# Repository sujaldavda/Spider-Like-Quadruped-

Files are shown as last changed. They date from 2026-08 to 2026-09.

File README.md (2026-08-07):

Quadruped Robot

A 4-legged, 12-DOF quadruped robot designed and developed
to explore mechanical design, electronics integration,
robot kinematics and coordinated multi-servo control.

Demo Video:
https://drive.google.com/file/d/1aahqjPfIVHdNBdxC4B8d9cbAuSaYIsEc/view

Hardware:
- ESP8266
- 12x SG90 Servo Motors
- PCA9685 Servo Driver
- XL4015 Buck Converter
- 2S 18650 Battery Pack

Mechanical Design:
- 3 DOF per leg
- 12 DOF total
- 3D printed structure
- CAD designed in SolidWorks

Control:
- Forward Kinematics
- Inverse Kinematics
- Coordinated gait control

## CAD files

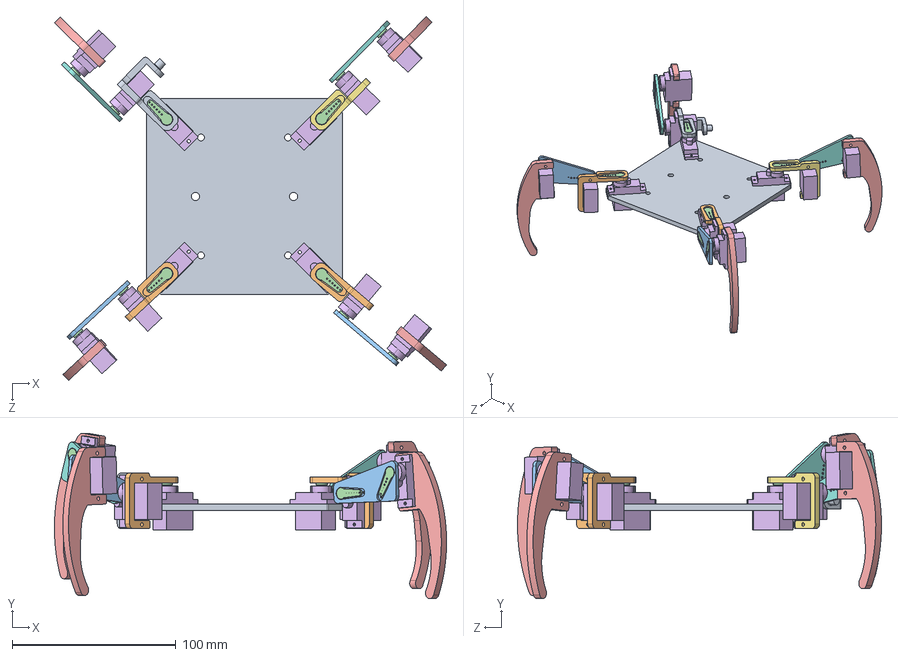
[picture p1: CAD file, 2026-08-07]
robot_description/CAD files/assembly.SLDASM
239.6 x 101.0 x 222.4 mm
base 5.0
clamp 1 redesigned x 2
mid clamp redesign x 2
servo horn x 12
tibia RD x 4
Servo_motor.step x 12
Mirrorclamp 1 redesigned
Mirrormid clamp redesign-------------------- x 2
clamp 1 remake

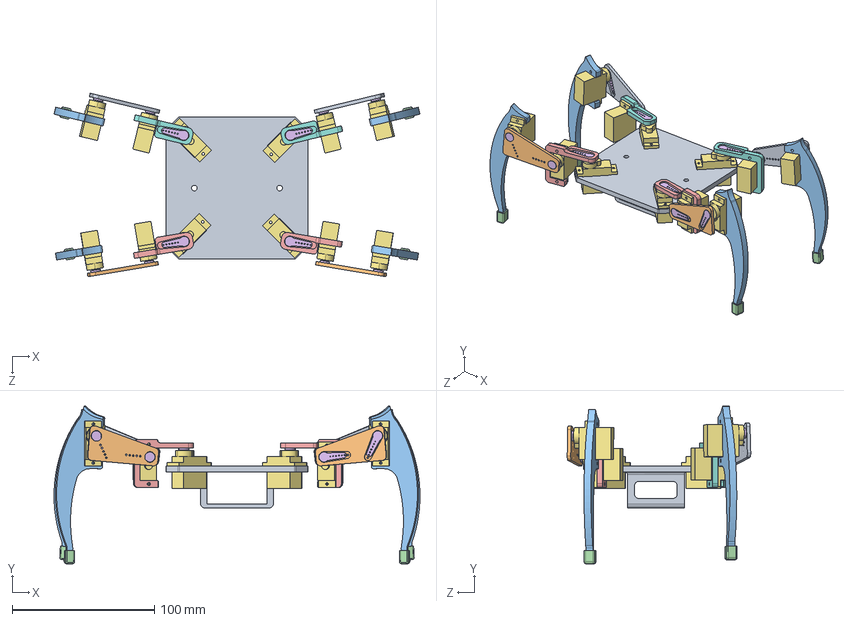
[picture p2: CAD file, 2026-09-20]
robot_description/meshes/Assem IK.SLDASM
257.5 x 110.9 x 129.2 mm
base 5.0 remake
mid clamp redesign x 2
tibia RD x 4
tibia tip x 4
clamp 1 redesigned x 2
servo horn x 12
Servo_motor.step x 12
Mirrorclamp 1 redesigned x 2
Mirrormid clamp redesign-------------------- x 2

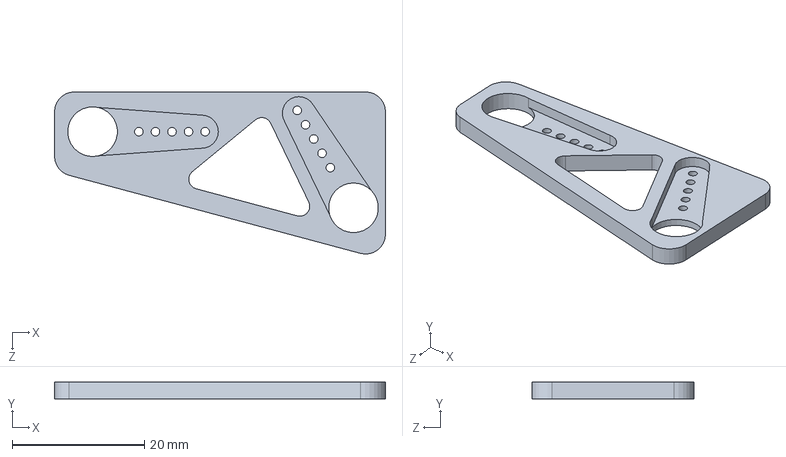
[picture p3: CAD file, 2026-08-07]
robot_description/CAD files/Mirrormid clamp redesign--------------------.SLDPRT
50.0 x 2.50 x 24.5 mm

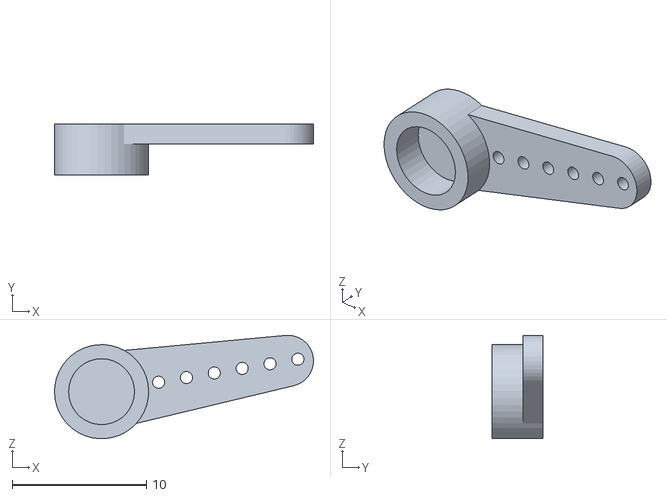
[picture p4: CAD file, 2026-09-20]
robot_description/meshes/quadrapod reddit - servo horn-1.STL
19.3 x 3.80 x 7.68

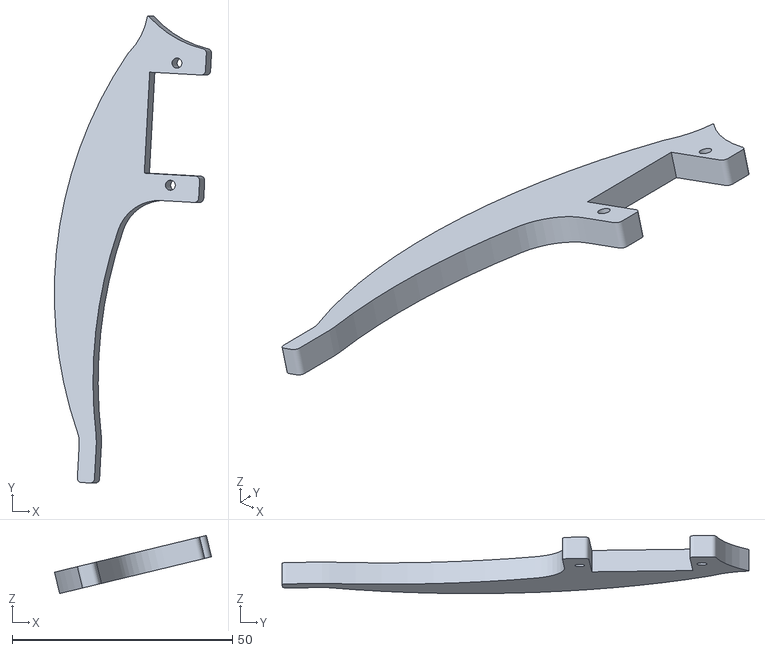
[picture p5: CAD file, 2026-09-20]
robot_description/meshes/quadrapod reddit - tibia RD-3.STL
35.7 x 106.1 x 13.2

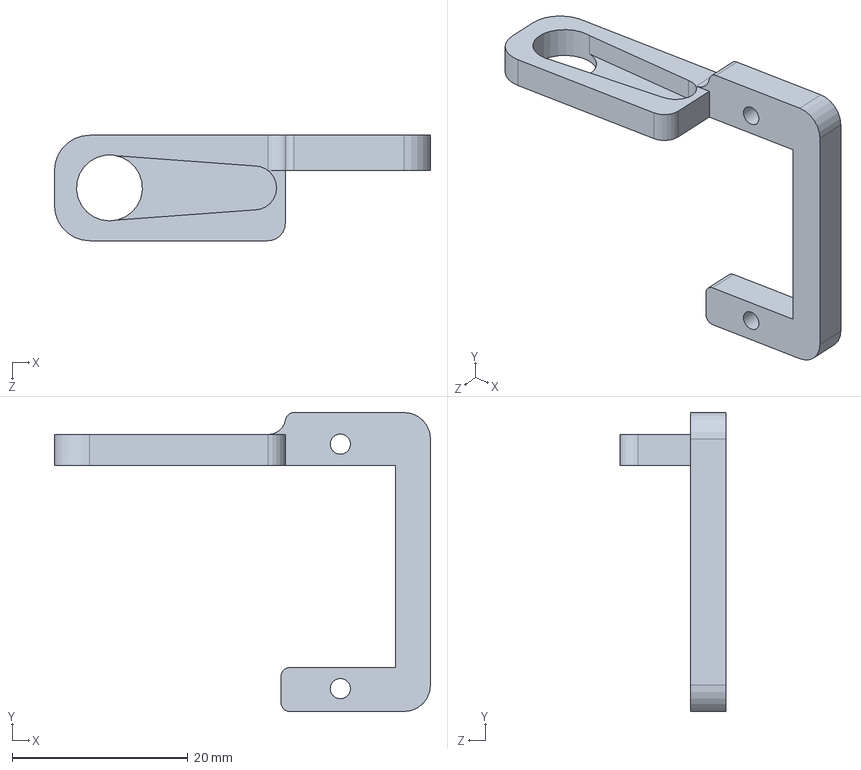
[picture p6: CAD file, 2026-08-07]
robot_description/CAD files/clamp 1 redesigned.SLDPRT
42.8 x 34.0 x 12.0 mm

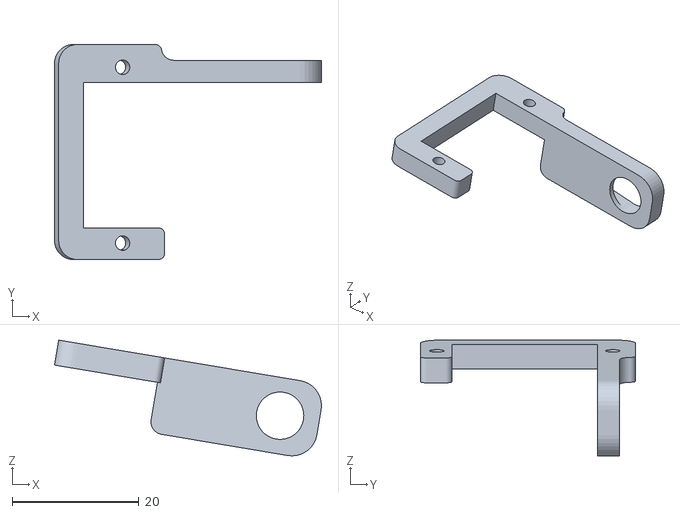
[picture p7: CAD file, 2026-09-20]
robot_description/meshes/quadrapod reddit - clamp 1 redesigned-2.STL
42.2 x 34.0 x 18.3

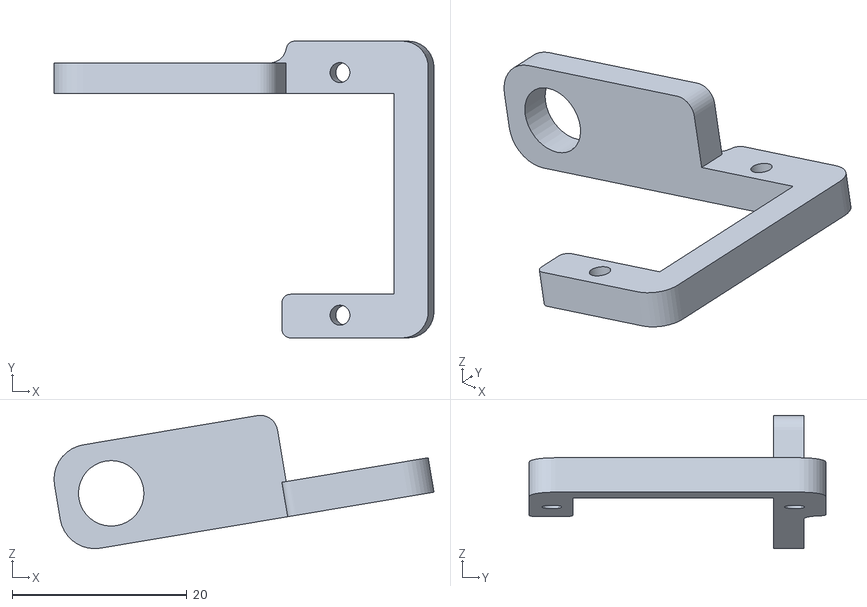
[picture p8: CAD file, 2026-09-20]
robot_description/meshes/quadrapod reddit - clamp 1 redesigned-1.STL
43.5 x 34.0 x 15.3

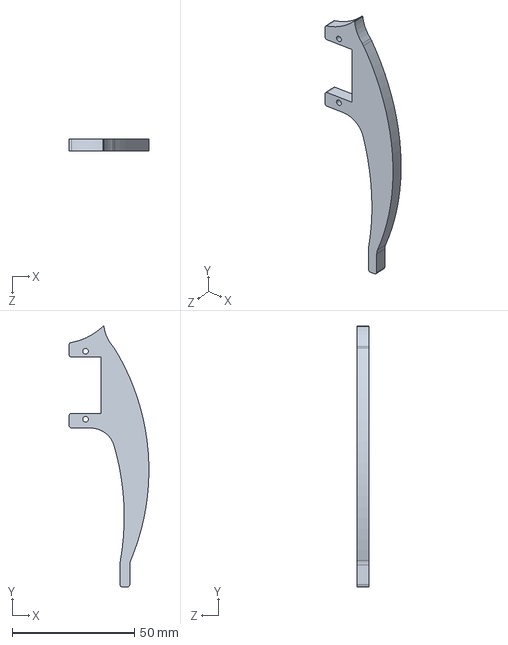
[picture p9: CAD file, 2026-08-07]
robot_description/CAD files/tibia RD.SLDPRT
32.6 x 106.7 x 5.00 mm

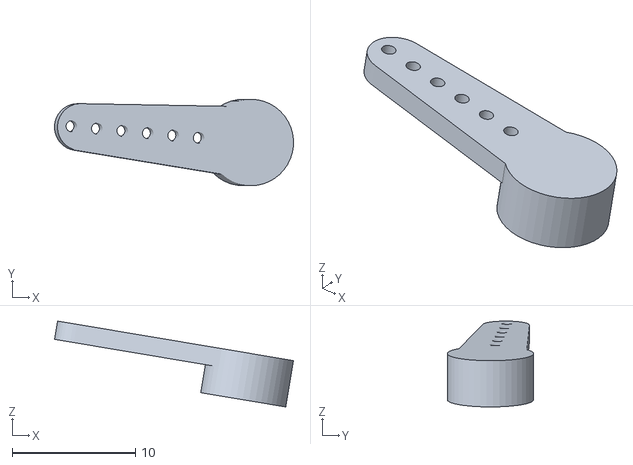
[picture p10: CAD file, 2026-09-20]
robot_description/meshes/quadrapod reddit - servo horn-11.STL
19.4 x 7.00 x 6.96

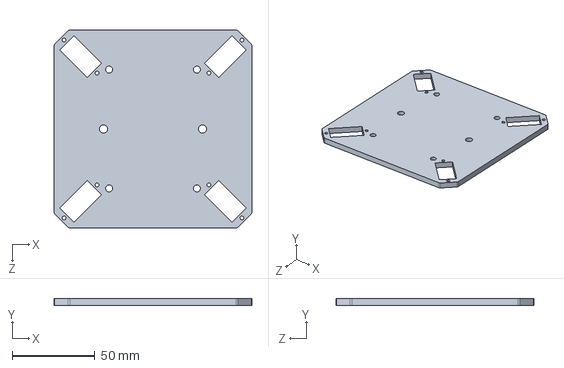
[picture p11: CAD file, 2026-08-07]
robot_description/CAD files/base 5.0.SLDPRT
120.0 x 4.00 x 120.0 mm

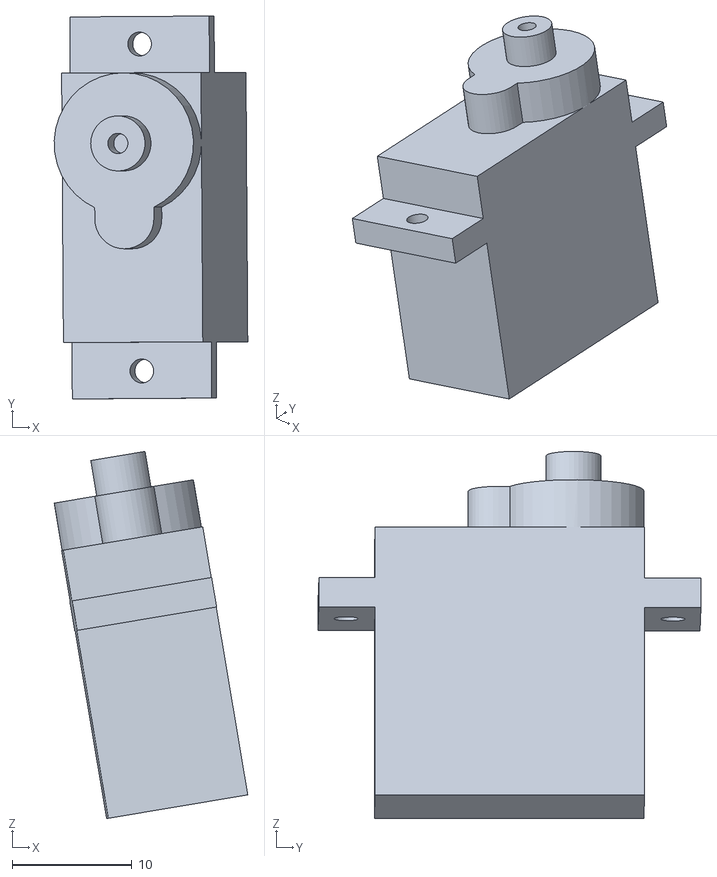
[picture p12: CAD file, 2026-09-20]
robot_description/meshes/quadrapod reddit - Servo_motor.step-3.STL
16.2 x 32.0 x 30.7

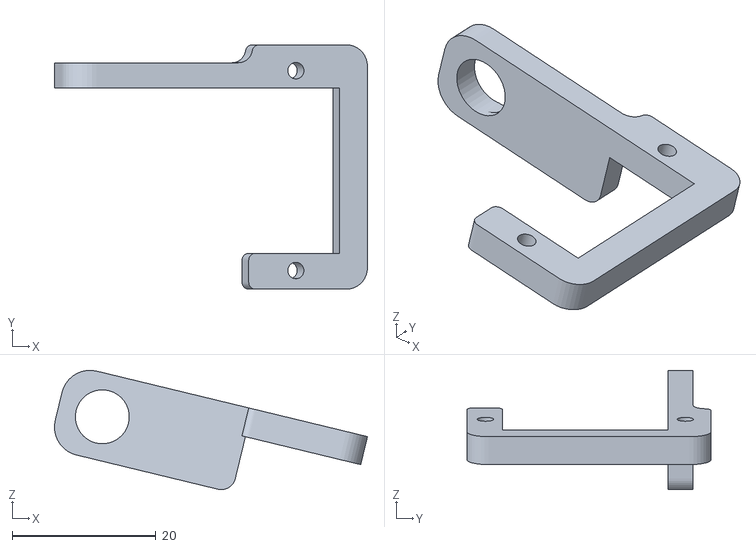
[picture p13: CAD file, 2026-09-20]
robot_description/meshes/quadrapod reddit - Mirrorclamp 1 redesigned-1.STL
43.5 x 34.0 x 16.6

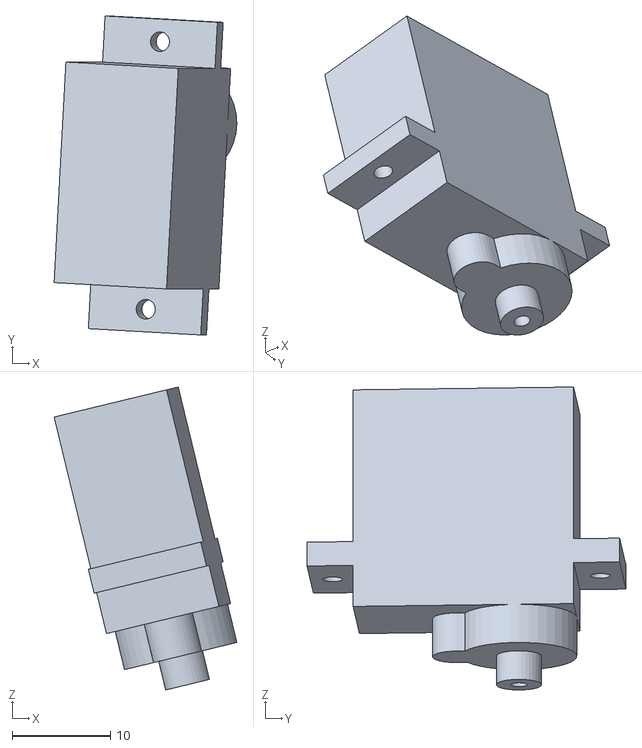
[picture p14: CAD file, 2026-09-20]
robot_description/meshes/quadrapod reddit - Servo_motor.step-10.STL
18.6 x 32.5 x 30.9

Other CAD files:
robot_description/CAD files/mid clamp redesign.SLDPRT
robot_description/CAD files/Mirrorclamp 1 redesigned.SLDPRT
robot_description/meshes/quadrapod reddit - servo horn-12.STL
robot_description/meshes/quadrapod reddit - Servo_motor.step-11.STL
robot_description/meshes/quadrapod reddit - Mirrorclamp 1 redesigned-2.STL
robot_description/meshes/quadrapod reddit - Mirrormid clamp redesign---------------------1.STL
robot_description/meshes/quadrapod reddit - Mirrormid clamp redesign---------------------2.STL
robot_description/meshes/quadrapod reddit - Servo_motor.step-1.STL
robot_description/meshes/quadrapod reddit - Servo_motor.step-12.STL
robot_description/meshes/quadrapod reddit - Servo_motor.step-2.STL
robot_description/meshes/quadrapod reddit - Servo_motor.step-4.STL
robot_description/meshes/quadrapod reddit - Servo_motor.step-5.STL
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

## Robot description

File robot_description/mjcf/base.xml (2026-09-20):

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
<mujoco model="spider_quadruped">
  <compiler angle="radian" meshdir="../meshes/" autolimits="true"/>
  <option timestep="0.001" integrator="implicitfast"/>

  <default>
    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
    <joint damping="0.02" armature="0.0005" frictionloss="0.001" range="-1.5708 1.5708"/>
    <position kp="3" kv="0.03" forcerange="-0.2 0.2" inheritrange="1"/>
    <default class="visual">
      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
      <default class="servo">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</default>
      <default class="horn">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</default>
    </default>
    <default class="collision">
      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
    </default>
  </default>

  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

  <worldbody>
    <body name="base_link" pos="0 0 0.06" childclass="visual">
      <freejoint name="root"/>
      <inertial pos="0 0 0.0086" mass="0.2025" fullinertia="7.194e-05 7.012e-05 1.310e-04 0 0 0"/>
      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
      <body name="FL_coxa" pos="0.03752 0.037166 0.02855">
        <joint name="FL_coxa_joint" axis="0 0 1" range="-1.5708 0.5236"/>
        <inertial pos="-0.00046952 0.025303 -0.011077" mass="0.010901" fullinertia="1.3433e-06 1.1827e-06 1.1172e-06 7.7895e-08 -6.036e-08 2.6762e-07"/>
        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
        <body name="FL_femur" pos="0.016051 0.024277 -0.0074">
          <joint name="FL_femur_joint" axis="0.9862 -0.1656 0"/>
          <inertial pos="0.0037466 0.020988 0.0058263" mass="0.0024496" fullinertia="6.2957e-07 1.2071e-07 5.4206e-07 -8.8356e-08 -2.2326e-08 -1.359e-07"/>
          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
          <body name="FL_tibia" pos="0.0063376 0.037747 0.014863">
            <joint name="FL_tibia_joint" axis="0.9862 -0.1656 0" range="-0.9948 1.5708"/>
            <inertial pos="-0.015733 0.0077231 -0.013664" mass="0.014061" fullinertia="7.1221e-06 6.6603e-06 1.4786e-06 -1.1556e-07 2.9199e-07 1.6351e-06"/>
            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
          </body>
        </body>
      </body>

      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
      <body name="RL_coxa" pos="-0.037166 0.03752 0.02855">
        <joint name="RL_coxa_joint" axis="0 0 1" range="-0.5760 1.5708"/>
        <inertial pos="-0.0013273 0.025273 -0.010665" mass="0.010901" fullinertia="1.3421e-06 1.161e-06 1.1172e-06 -6.574e-08 4.0386e-08 2.6305e-07"/>
        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
        <body name="RL_femur" pos="-0.017733 0.023077 -0.0069">
          <joint name="RL_femur_joint" axis="-0.972 -0.2352 0"/>
          <inertial pos="-0.005173 0.020448 0.0066131" mass="0.0024496" fullinertia="6.1528e-07 1.4603e-07 5.3144e-07 1.2108e-07 3.5638e-08 -1.4931e-07"/>
          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
          <body name="RL_tibia" pos="-0.0088641 0.036639 0.016275">
            <joint name="RL_tibia_joint" axis="-0.972 -0.2352 0" range="-1.5708 0.9948"/>
            <inertial pos="0.014988 0.0094516 -0.013408" mass="0.014061" fullinertia="7.0932e-06 6.518e-06 1.65e-06 1.8779e-07 -4.667e-07 1.8427e-06"/>
            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
          </body>
        </body>
      </body>

      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
      <body name="RR_coxa" pos="-0.03752 -0.037166 0.02855">
        <joint name="RR_coxa_joint" axis="0 0 1" range="-1.5708 0.5760"/>
        <inertial pos="-0.0015781 -0.02548 -0.010665" mass="0.010901" fullinertia="1.3287e-06 1.2335e-06 1.1761e-06 4.6707e-08 3.4993e-08 -2.6174e-07"/>
        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
        <body name="RR_femur" pos="-0.01738 -0.023431 -0.0069">
          <joint name="RR_femur_joint" axis="-0.972 0.2352 0"/>
          <inertial pos="-0.0052527 -0.020428 0.0066131" mass="0.0024496" fullinertia="6.1521e-07 1.461e-07 5.3144e-07 -1.2122e-07 3.5146e-08 1.4943e-07"/>
          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
          <body name="RR_tibia" pos="-0.0088641 -0.036639 0.016275">
            <joint name="RR_tibia_joint" axis="-0.972 0.2352 0" range="-1.0996 1.5708"/>
            <inertial pos="0.014988 -0.0094516 -0.013408" mass="0.014061" fullinertia="7.0932e-06 6.518e-06 1.65e-06 -1.8779e-07 -4.667e-07 -1.8427e-06"/>
            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
          </body>
        </body>
      </body>

      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
      <body name="FR_coxa" pos="0.037166 -0.03752 0.02855">
        <joint name="FR_coxa_joint" axis="0 0 1" range="-0.5236 1.5708"/>
        <inertial pos="0.00049728 -0.024847 -0.011077" mass="0.010901" fullinertia="1.333e-06 1.252e-06 1.1761e-06 -5.2976e-08 -5.7648e-08 -2.6716e-07"/>
        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
        <body name="FR_femur" pos="0.016404 -0.023924 -0.0074">
          <joint name="FR_femur_joint" axis="0.9862 0.1656 0"/>
          <inertial pos="0.0038275 -0.020974 0.0058263" mass="0.0024496" fullinertia="6.2952e-07 1.2075e-07 5.4205e-07 8.8493e-08 -2.1821e-08 1.3599e-07"/>
          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
          <body name="FR_tibia" pos="0.0063376 -0.037747 0.014863">
            <joint name="FR_tibia_joint" axis="0.9862 0.1656 0" range="-1.5708 0.9948"/>
            <inertial pos="-0.015733 -0.0077231 -0.013664" mass="0.014061" fullinertia="7.1221e-06 6.6603e-06 1.4786e-06 1.1556e-07 2.9199e-07 -1.6351e-06"/>
            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
          </body>
        </body>
      </body>
    </body>
  </worldbody>

  <actuator>
    <position name="FL_coxa" joint="FL_coxa_joint"/>
    <position name="FL_femur" joint="FL_femur_joint"/>
    <position name="FL_tibia" joint="FL_tibia_joint"/>
    <position name="RL_coxa" joint="RL_coxa_joint"/>
    <position name="RL_femur" joint="RL_femur_joint"/>
    <position name="RL_tibia" joint="RL_tibia_joint"/>
    <position name="RR_coxa" joint="RR_coxa_joint"/>
    <position name="RR_femur" joint="RR_femur_joint"/>
    <position name="RR_tibia" joint="RR_tibia_joint"/>
    <position name="FR_coxa" joint="FR_coxa_joint"/>
    <position name="FR_femur" joint="FR_femur_joint"/>
    <position name="FR_tibia" joint="FR_tibia_joint"/>
  </actuator>

  <sensor>
    <framequat name="imu_quat" objtype="site" objname="imu"/>
    <gyro name="imu_gyro" site="imu"/>
    <accelerometer name="imu_acc" site="imu"/>
  </sensor>

  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
</mujoco>

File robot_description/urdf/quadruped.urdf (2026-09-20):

<?xml version="1.0"?>
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
<robot name="spider_quadruped">

  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
  <link name="base_link">
    <inertial>
      <origin xyz="0 0 0.0086" rpy="0 0 0"/>
      <mass value="0.2025"/>
      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
    </inertial>
    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
  </link>

  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
  <joint name="FL_coxa_joint" type="revolute">
    <parent link="base_link"/><child link="FL_coxa"/>
    <origin xyz="0.03752 0.037166 0.02855" rpy="0 0 0"/>
    <axis xyz="0 0 1"/>
    <limit lower="-1.5708" upper="0.5236" effort="0.2" velocity="10.5"/>
    <dynamics damping="0.02" friction="0.0"/>
  </joint>
  <link name="FL_coxa">
    <inertial>
      <origin xyz="-0.00046952 0.025303 -0.011077" rpy="0 0 0"/>
      <mass value="0.010901"/>
      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
    </inertial>
    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
  </link>

  <joint name="FL_femur_joint" type="revolute">
    <parent link="FL_coxa"/><child link="FL_femur"/>
    <origin xyz="0.016051 0.024277 -0.0074" rpy="0 0 0"/>
    <axis xyz="0.9862 -0.1656 0"/>
    <limit lower="-1.5708" upper="1.5708" effort="0.2" velocity="10.5"/>
    <dynamics damping="0.02" friction="0.0"/>
  </joint>
  <link name="FL_femur">
    <inertial>
      <origin xyz="0.0037466 0.020988 0.0058263" rpy="0 0 0"/>
      <mass value="0.0024496"/>
      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
    </inertial>
    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
  </link>

  <joint name="FL_tibia_joint" type="revolute">
    <parent link="FL_femur"/><child link="FL_tibia"/>
    <origin xyz="0.0063376 0.037747 0.014863" rpy="0 0 0"/>
    <axis xyz="0.9862 -0.1656 0"/>
    <limit lower="-0.9948" upper="1.5708" effort="0.2" velocity="10.5"/>
    <dynamics damping="0.02" friction="0.0"/>
  </joint>
  <link name="FL_tibia">
    <inertial>
      <origin xyz="-0.015733 0.0077231 -0.013664" rpy="0 0 0"/>
      <mass value="0.014061"/>
      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
    </inertial>
    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
  </link>

  <joint name="FL_foot_joint" type="fixed">
    <parent link="FL_tibia"/><child link="FL_foot"/>
    <origin xyz="-0.01356 0.018587 -0.089869" rpy="0 0 0"/>
  </joint>
  <link name="FL_foot"/>

  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
  <joint name="RL_coxa_joint" type="revolute">
    <parent link="base_link"/><child link="RL_coxa"/>
    <origin xyz="-0.037166 0.03752 0.02855" rpy="0 0 0"/>
    <axis xyz="0 0 1"/>
    <limit lower="-0.5760" upper="1.5708" effort="0.2" velocity="10.5"/>
    <dynamics damping="0.02" friction="0.0"/>
  </joint>
  <link name="RL_coxa">
    <inertial>
      <origin xyz="-0.0013273 0.025273 -0.010665" rpy="0 0 0"/>
      <mass value="0.010901"/>
      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
    </inertial>
    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
  </link>

  <joint name="RL_femur_joint" type="revolute">
    <parent link="RL_coxa"/><child link="RL_femur"/>
    <origin xyz="-0.017733 0.023077 -0.0069" rpy="0 0 0"/>
    <axis xyz="-0.972 -0.2352 0"/>
    <limit lower="-1.5708" upper="1.5708" effort="0.2" velocity="10.5"/>
    <dynamics damping="0.02" friction="0.0"/>
  </joint>
  <link name="RL_femur">
    <inertial>
      <origin xyz="-0.005173 0.020448 0.0066131" rpy="0 0 0"/>
      <mass value="0.0024496"/>
      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
    </inertial>
    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
  </link>

  <joint name="RL_tibia_joint" type="revolute">
    <parent link="RL_femur"/><child link="RL_tibia"/>
    <origin xyz="-0.0088641 0.036639 0.016275" rpy="0 0 0"/>
    <axis xyz="-0.972 -0.2352 0"/>
    <limit lower="-1.5708" upper="0.9948" effort="0.2" velocity="10.5"/>
    <dynamics damping="0.02" friction="0.0"/>
  </joint>
  <link name="RL_tibia">
    <inertial>
      <origin xyz="0.014988 0.0094516 -0.013408" rpy="0 0 0"/>
      <mass value="0.014061"/>
      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
    </inertial>
    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
  </link>

  <joint name="RL_foot_joint" type="fixed">
    <parent link="RL_tibia"/><child link="RL_foot"/>
    <origin xyz="0.011155 0.022571 -0.089045" rpy="0 0 0"/>
  </joint>
  <link name="RL_foot"/>

  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
  <joint name="RR_coxa_joint" type="revolute">
    <parent link="base_link"/><child link="RR_coxa"/>
    <origin xyz="-0.03752 -0.037166 0.02855" rpy="0 0 0"/>
    <axis xyz="0 0 1"/>
    <limit lower="-1.5708" upper="0.5760" effort="0.2" velocity="10.5"/>
    <dynamics damping="0.02" friction="0.0"/>
  </joint>
  <link name="RR_coxa">
    <inertial>
      <origin xyz="-0.0015781 -0.02548 -0.010665" rpy="0 0 0"/>
      <mass value="0.010901"/>
      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
    </inertial>
    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
  </link>

  <joint name="RR_femur_joint" type="revolute">
    <parent link="RR_coxa"/><child link="RR_femur"/>
    <origin xyz="-0.01738 -0.023431 -0.0069" rpy="0 0 0"/>
    <axis xyz="-0.972 0.2352 0"/>
    <limit lower="-1.5708" upper="1.5708" effort="0.2" velocity="10.5"/>
    <dynamics damping="0.02" friction="0.0"/>
  </joint>
  <link name="RR_femur">
    <inertial>
      <origin xyz="-0.0052527 -0.020428 0.0066131" rpy="0 0 0"/>
      <mass value="0.0024496"/>
      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
    </inertial>
    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
  </link>

  <joint name="RR_tibia_joint" type="revolute">
    <parent link="RR_femur"/><child link="RR_tibia"/>
    <origin xyz="-0.0088641 -0.036639 0.016275" rpy="0 0 0"/>
    <axis xyz="-0.972 0.2352 0"/>
    <limit lower="-1.0996" upper="1.5708" effort="0.2" velocity="10.5"/>
    <dynamics damping="0.02" friction="0.0"/>
  </joint>
  <link name="RR_tibia">
    <inertial>
      <origin xyz="0.014988 -0.0094516 -0.013408" rpy="0 0 0"/>
      <mass value="0.014061"/>
      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
    </inertial>
    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
  </link>

  <joint name="RR_foot_joint" type="fixed">
    <parent link="RR_tibia"/><child link="RR_foot"/>
    <origin xyz="0.011155 -0.022571 -0.089045" rpy="0 0 0"/>
  </joint>
  <link name="RR_foot"/>

  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
  <joint name="FR_coxa_joint" type="revolute">
    <parent link="base_link"/><child link="FR_coxa"/>
    <origin xyz="0.037166 -0.03752 0.02855" rpy="0 0 0"/>
    <axis xyz="0 0 1"/>
    <limit lower="-0.5236" upper="1.5708" effort="0.2" velocity="10.5"/>
    <dynamics damping="0.02" friction="0.0"/>
  </joint>
  <link name="FR_coxa">
    <inertial>
      <origin xyz="0.00049728 -0.024847 -0.011077" rpy="0 0 0"/>
      <mass value="0.010901"/>
      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
    </inertial>
    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
  </link>

  <joint name="FR_femur_joint" type="revolute">
    <parent link="FR_coxa"/><child link="FR_femur"/>
    <origin xyz="0.016404 -0.023924 -0.0074" rpy="0 0 0"/>
    <axis xyz="0.9862 0.1656 0"/>
    <limit lower="-1.5708" upper="1.5708" effort="0.2" velocity="10.5"/>
    <dynamics damping="0.02" friction="0.0"/>
  </joint>
  <link name="FR_femur">
    <inertial>
      <origin xyz="0.0038275 -0.020974 0.0058263" rpy="0 0 0"/>
      <mass value="0.0024496"/>
      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
    </inertial>
    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
  </link>
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

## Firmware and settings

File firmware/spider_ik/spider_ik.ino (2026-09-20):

// =====================================================
// SPIDER-LIKE QUADRUPED - 3-DOF IK (all 4 legs)
// ESP8266 + PCA9685 + 12x SG90
// =====================================================
// Coordinates: body frame, mm. Origin = centre of base plate,
// x forward, y left, z up. Same frame as model/quadruped.urdf.
// Joint angles: deg, 0 = CAD assembly pose.
//
// Serial 115200, commands (one per line):
//   help
//   home                      all feet to CAD pose
//   foot FL x y z             move foot to body-frame target
//   rel FL dx dy dz           move foot relative to its home position
//   height dz                 all feet shifted dz from home (negative = body up)
//   joint FL coxa femur tibia set joint angles directly
//   raw ch deg                raw servo angle 0-180 (calibration)
//   where                     print feet and joint angles
// Legs: FL RL RR FR
// =====================================================

#include <Wire.h>
#include <Adafruit_PWMServoDriver.h>
#include "leg_ik.h"

using namespace leg_ik;

Adafruit_PWMServoDriver pca = Adafruit_PWMServoDriver(0x40);

// =====================================================
// PCA9685 / SG90
// =====================================================
#define SERVO_FREQ 50
#define SERVO_MIN 102   // pulse ticks at 0 deg   (~0.5 ms)
#define SERVO_MAX 512   // pulse ticks at 180 deg (~2.5 ms)

// =====================================================
// CALIBRATION  <-- EDIT FOR YOUR ROBOT
// =====================================================
// Index = leg*3 + joint, legs FL RL RR FR, joints coxa femur tibia.
//
// SERVO_CHANNEL: PCA9685 output for each joint.
// SERVO_CENTER : raw servo angle (0-180) that puts the joint in the CAD pose.
//                Find it with "raw ch deg" until the leg matches the CAD.
// SERVO_DIR    : +1 or -1, so positive joint angles move the way the model expects:
//                coxa  +  = leg swings counter-clockwise seen from above (all legs)
//                femur +  = foot UP on FL and RR, foot DOWN on RL and FR
//                tibia +  = foot tip swings outward on FL and RR, inward on RL and FR
//                Test with e.g. "joint FL 0 10 0" and flip the sign if it moves the wrong way.
const uint8_t SERVO_CHANNEL[12] = {
  0, 1, 2,     // FL
  3, 4, 5,     // RL
  6, 7, 8,     // RR
  9, 10, 11    // FR
};
float SERVO_CENTER[12] = {
  90, 90, 90,
  90, 90, 90,
  90, 90, 90,
  90, 90, 90
};
int8_t SERVO_DIR[12] = {
  1, 1, 1,
  1, 1, 1,
  1, 1, 1,
  1, 1, 1
};

// =====================================================
// MOTION
// =====================================================
const unsigned long MOVE_MS = 400;   // duration of a foot move
const unsigned long STEP_MS = 20;    // update period (one servo frame)

float homePos[4][3];   // foot positions at CAD pose
float curPos[4][3];    // current commanded foot positions
Joints curJoints[4];

// =====================================================
// SERVO OUTPUT
// =====================================================
void writeServoRaw(uint8_t index, float deg)
{
  deg = constrain(deg, 0.0, 180.0);
  int pulse = SERVO_MIN + (int)(deg / 180.0 * (SERVO_MAX - SERVO_MIN) + 0.5);
  pca.setPWM(SERVO_CHANNEL[index], 0, pulse);
}

bool writeLeg(int leg, const Joints &q)
{
  float qa[3] = {q.coxa, q.femur, q.tibia};
  float raw[3];
  for (int j = 0; j < 3; j++) {
    int i = leg * 3 + j;
    raw[j] = SERVO_CENTER[i] + SERVO_DIR[i] * qa[j];
    if (raw[j] < 0 || raw[j] > 180) {
      Serial.printf("ERROR: %s joint %d needs servo %.1f deg (outside 0-180), check SERVO_CENTER\n",
                    LEGS[leg].name, j, raw[j]);
      return false;
    }
  }
  for (int j = 0; j < 3; j++) writeServoRaw(leg * 3 + j, raw[j]);
  curJoints[leg] = q;
  return true;
}

// =====================================================
// IK WRAPPERS
// =====================================================
const char *resultText(Result r)
{
  switch (r) {
    case TOO_CLOSE:    return "target too close to coxa axis";
    case OUT_OF_REACH: return "target out of reach";
    case JOINT_LIMIT:  return "joint limit";
    default:           return "ok";
  }
}

bool solveLeg(int leg, float x, float y, float z, Joints &q)
{
  Result r = inverse(LEGS[leg], x, y, z, q);
  if (r != OK) {
    Serial.printf("ERROR: %s -> (%.1f, %.1f, %.1f): %s", LEGS[leg].name, x, y, z, resultText(r));
    if (r == JOINT_LIMIT) Serial.printf(" (coxa %.1f femur %.1f tibia %.1f)", q.coxa, q.femur, q.tibia);
    Serial.println();
    return false;
  }
  return true;
}

// Move several feet together along straight lines. Checks the whole path first.
bool moveFeet(float target[4][3], bool active[4])
{
  int steps = max(1UL, MOVE_MS / STEP_MS);
  Joints q[4];

  for (int k = 1; k <= steps; k++) {
    float t = (float)k / steps;
    for (int leg = 0; leg < 4; leg++) {
      if (!active[leg]) continue;
      float p[3];
      for (int a = 0; a < 3; a++) p[a] = curPos[leg][a] + (target[leg][a] - curPos[leg][a]) * t;
      if (!solveLeg(leg, p[0], p[1], p[2], q[leg])) return false;
    }
  }

  unsigned long next = millis();
  for (int k = 1; k <= steps; k++) {
    float t = (float)k / steps;
    for (int leg = 0; leg < 4; leg++) {
      if (!active[leg]) continue;
      float p[3];
      for (int a = 0; a < 3; a++) p[a] = curPos[leg][a] + (target[leg][a] - curPos[leg][a]) * t;
      solveLeg(leg, p[0], p[1], p[2], q[leg]);
      if (!writeLeg(leg, q[leg])) return false;
    }
    next += STEP_MS;
    while (millis() < next) delay(1);
  }
  for (int leg = 0; leg < 4; leg++)
    if (active[leg])
      for (int a = 0; a < 3; a++) curPos[leg][a] = target[leg][a];
  return true;
}

bool moveOneFoot(int leg, float x, float y, float z)
{
  float target[4][3];
  bool active[4] = {false, false, false, false};
  memcpy(target, curPos, sizeof(target));
  target[leg][0] = x; target[leg][1] = y; target[leg][2] = z;
  active[leg] = true;
  return moveFeet(target, active);
}

// =====================================================
// SERIAL COMMANDS
// =====================================================
int legIndex(const char *s)
{
  if (!s) return -1;
  for (int i = 0; i < 4; i++)
    if (toupper(s[0]) == LEGS[i].name[0] && toupper(s[1]) == LEGS[i].name[1] && s[2] == 0) return i;
  return -1;
}

bool readFloats(float *out, int n)
{
  for (int i = 0; i < n; i++) {
    char *tok = strtok(NULL, " ,\t");
    if (!tok) return false;
    out[i] = atof(tok);
  }
  return true;
}

void printWhere()
{
  for (int leg = 0; leg < 4; leg++)
    Serial.printf("%s foot (%.1f, %.1f, %.1f) mm  joints coxa %.1f femur %.1f tibia %.1f deg\n",
                  LEGS[leg].name, curPos[leg][0], curPos[leg][1], curPos[leg][2],
                  curJoints[leg].coxa, curJoints[leg].femur, curJoints[leg].tibia);
}

void printHelp()
{
  Serial.println("home | foot FL x y z | rel FL dx dy dz | height dz | joint FL c f t | raw ch deg | where");
  Serial.println("legs: FL RL RR FR   units: mm, deg   frame: x forward, y left, z up");
}

void handleCommand(char *line)
{
  char *cmd = strtok(line, " ,\t");
  if (!cmd) return;
  float v[4];

  if (!strcmp(cmd, "help")) {
    printHelp();
  }
  else if (!strcmp(cmd, "home")) {
    bool all[4] = {true, true, true, true};
    moveFeet(homePos, all);
  }
  else if (!strcmp(cmd, "foot") || !strcmp(cmd, "rel")) {
    int leg = legIndex(strtok(NULL, " ,\t"));
    if (leg < 0 || !readFloats(v, 3)) { Serial.println("usage: foot FL x y z | rel FL dx dy dz"); return; }
    if (!strcmp(cmd, "rel")) for (int a = 0; a < 3; a++) v[a] += homePos[leg][a];
    moveOneFoot(leg, v[0], v[1], v[2]);
  }
  else if (!strcmp(cmd, "height")) {
    if (!readFloats(v, 1)) { Serial.println("usage: height dz"); return; }
    float target[4][3];
    bool all[4] = {true, true, true, true};
    for (int leg = 0; leg < 4; leg++) {
      target[leg][0] = homePos[leg][0];
      target[leg][1] = homePos[leg][1];
      target[leg][2] = homePos[leg][2] + v[0];
    }
    moveFeet(target, all);
  }
  else if (!strcmp(cmd, "joint")) {
    int leg = legIndex(strtok(NULL, " ,\t"));
    if (leg < 0 || !readFloats(v, 3)) { Serial.println("usage: joint FL coxa femur tibia"); return; }
    Joints q = {v[0], v[1], v[2]};
    const LegGeom &g = LEGS[leg];
    for (int j = 0; j < 3; j++)
      if (v[j] < g.minDeg[j] || v[j] > g.maxDeg[j]) { Serial.printf("ERROR: joint %d outside %.0f..%.0f\n", j, g.minDeg[j], g.maxDeg[j]); return; }
    if (writeLeg(leg, q)) forward(g, q, curPos[leg][0], curPos[leg][1], curPos[leg][2]);
  }
  else if (!strcmp(cmd, "raw")) {
    if (!readFloats(v, 2) || v[0] < 0 || v[0] > 15) { Serial.println("usage: raw ch deg"); return; }
    int ch = (int)v[0];
    float deg = constrain(v[1], 0.0, 180.0);
    pca.setPWM(ch, 0, SERVO_MIN + (int)(deg / 180.0 * (SERVO_MAX - SERVO_MIN) + 0.5));
    Serial.printf("channel %d -> %.1f deg\n", ch, deg);
    return;
  }
  else if (!strcmp(cmd, "where")) {
    printWhere();
    return;
  }
  else {
    Serial.println("unknown command, type help");
    return;
  }
  printWhere();
}

// =====================================================
// SETUP / LOOP
// =====================================================
void setup()
{
  Serial.begin(115200);
  Wire.begin();
  pca.begin();
  pca.setOscillatorFrequency(27000000);
  pca.setPWMFreq(SERVO_FREQ);
  delay(500);

  Joints zero = {0, 0, 0};
  for (int leg = 0; leg < 4; leg++) {
    forward(LEGS[leg], zero, homePos[leg][0], homePos[leg][1], homePos[leg][2]);
    memcpy(curPos[leg], homePos[leg], sizeof(homePos[leg]));
    writeLeg(leg, zero);
  }

  Serial.println();
  Serial.println("================================");
  Serial.println("   QUADRUPED 3-DOF IK READY");
  Serial.println("================================");
  printHelp();
  printWhere();
}

void loop()
{
  static char buf[96];
  static uint8_t len = 0;
  while (Serial.available()) {
    char c = Serial.read();
    if (c == '\r') continue;
    if (c == '\n') {
      buf[len] = 0;
      handleCommand(buf);
      len = 0;
    } else if (len < sizeof(buf) - 1) {
      buf[len++] = c;
    }
  }
}

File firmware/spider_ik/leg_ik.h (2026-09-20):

// =====================================================
// 3-DOF LEG INVERSE KINEMATICS
// =====================================================
// Pure C++ (no Arduino dependencies) so it can be tested on a PC.
//
// Body frame (same as model/quadruped.urdf):
//   origin = centre of base plate, x forward, y left, z up, units mm.
// Joint angles are in degrees with the same zero and sign as the URDF/MJCF:
//   0,0,0 = CAD assembly pose.
//
// Geometry below was measured from the CAD (see model/).
#pragma once
#include <math.h>

namespace leg_ik {

const float DEG = 180.0f / 3.14159265f;

struct LegGeom {
  const char *name;
  float cx, cy, cz;     // coxa axis point (top of coxa servo shaft), body frame
  float psi0;           // leg heading at coxa = 0, deg
  float d;              // sideways offset of leg plane from coxa axis (+ = left of heading)
  float r0, h0;         // femur shaft relative to coxa shaft: outward, up
  float Lf, b1;         // femur shaft -> tibia shaft length, its angle above horizontal at pose 0 (deg)
  float Lt, b2;         // tibia shaft -> foot tip length, its angle above horizontal at pose 0 (deg)
  float s;              // +1: positive femur/tibia angle lifts the foot, -1: lowers it
  float minDeg[3], maxDeg[3];  // joint limits (coxa, femur, tibia) from CAD collision sweep
};

// Order: FL, RL, RR, FR
const LegGeom LEGS[4] = {
  {"FL",  37.520f,  37.166f, 28.55f,   80.468f,  4.6424f, 26.5998f, -7.4f, 41.0598f, 21.2221f, 91.2971f, -79.8526f,  1.0f,
   {-90, -90, -57}, {30, 90, 90}},
  {"RL", -37.166f,  37.520f, 28.55f,  103.603f, -4.3440f, 26.6003f, -6.9f, 41.0593f, 23.3520f, 91.1156f, -77.7618f, -1.0f,
   {-33, -90, -90}, {90, 90, 57}},
  {"RR", -37.520f, -37.166f, 28.55f, -103.603f,  4.7703f, 26.8613f, -6.9f, 41.0593f, 23.3520f, 91.1156f, -77.7618f,  1.0f,
   {-90, -90, -63}, {33, 90, 90}},
  {"FR",  37.166f, -37.520f, 28.55f,  -80.468f, -4.2358f, 26.3102f, -7.4f, 41.0598f, 21.2221f, 91.2971f, -79.8526f, -1.0f,
   {-30, -90, -90}, {90, 90, 57}},
};

struct Joints { float coxa, femur, tibia; };  // deg

enum Result { OK = 0, TOO_CLOSE = 1, OUT_OF_REACH = 2, JOINT_LIMIT = 3 };

inline float wrap180(float a) {
  while (a > 180.0f) a -= 360.0f;
  while (a < -180.0f) a += 360.0f;
  return a;
}

inline float clampf(float v, float lo, float hi) { return v < lo ? lo : (v > hi ? hi : v); }

// Foot position (body frame, mm) from joint angles.
inline void forward(const LegGeom &g, const Joints &q, float &x, float &y, float &z) {
  float psi = (g.psi0 + q.coxa) / DEG;
  float a1 = g.b1 / DEG + g.s * q.femur / DEG;                 // femur angle above horizontal
  float a2 = g.b2 / DEG + g.s * (q.femur + q.tibia) / DEG;     // tibia angle above horizontal
  float R = g.r0 + g.Lf * cos(a1) + g.Lt * cos(a2);            // outward distance from coxa axis
  float Z = g.h0 + g.Lf * sin(a1) + g.Lt * sin(a2);
  x = g.cx + R * cos(psi) - g.d * sin(psi);
  y = g.cy + R * sin(psi) + g.d * cos(psi);
  z = g.cz + Z;
}

// Joint angles for a foot target (body frame, mm). Knee-up solution (same as the CAD pose).
// out is always filled when reachable; returns JOINT_LIMIT if any angle is outside the limits.
inline Result inverse(const LegGeom &g, float x, float y, float z, Joints &out) {
  float px = x - g.cx, py = y - g.cy, pz = z - g.cz;

  // 1) Coxa: rotate the leg plane so it contains the foot (plane is offset d from the axis)
  float rho2 = px * px + py * py;
  if (rho2 <= g.d * g.d + 1e-6f) return TOO_CLOSE;
  float R = sqrt(rho2 - g.d * g.d);
  float psi = atan2(py, px) - atan2(g.d, R);
  out.coxa = wrap180(psi * DEG - g.psi0);

  // 2) Femur + tibia: planar 2-link from the femur shaft
  float X = R - g.r0, Z = pz - g.h0;
  float L = sqrt(X * X + Z * Z);
  if (L > g.Lf + g.Lt || L < fabs(g.Lf - g.Lt) || L < 1e-6f) return OUT_OF_REACH;

  float phi = atan2(Z, X);                                                             // direction to foot
  float alpha = acos(clampf((g.Lf * g.Lf + L * L - g.Lt * g.Lt) / (2 * g.Lf * L), -1, 1));  // angle at femur shaft
  float gamma = acos(clampf((g.Lf * g.Lf + g.Lt * g.Lt - L * L) / (2 * g.Lf * g.Lt), -1, 1)); // interior knee angle

  float a1 = phi + alpha;                    // femur above the hip->foot line (knee up)
  float a2 = a1 - (3.14159265f - gamma);     // tibia bends down from the femur

  out.femur = wrap180(g.s * (a1 * DEG - g.b1));
  out.tibia = wrap180(g.s * ((a2 - a1) * DEG - (g.b2 - g.b1)));

  float qa[3] = {out.coxa, out.femur, out.tibia};
  for (int i = 0; i < 3; i++)
    if (qa[i] < g.minDeg[i] || qa[i] > g.maxDeg[i]) return JOINT_LIMIT;
  return OK;
}

}  // namespace leg_ik
